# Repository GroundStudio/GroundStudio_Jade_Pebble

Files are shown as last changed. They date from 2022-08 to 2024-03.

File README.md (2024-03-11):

GroundStudio Jade Pebble
====================================
KASV939 (https://ardushop.ro/ro/placi-de-dezvoltare/1724-placa-de-dezvoltare-jade-pebble.html)

Get it from [ardushop.ro](https://ardushop.ro/ro/placi-de-dezvoltare/1724-placa-de-dezvoltare-jade-pebble.html)

Explore all the GroundStudio products at [GroundStudio.ro](https://groundstudio.ro/)

Description
-------------------
Very small SAMD21E18A based development board wih 48 MHz 32 bit processor, 256kBytes of Programmable Flash program memory, 32kBytes Internal SRAM, 6 Capacitive Touch sensing (PTC), 9 PWM Channels, 11 Digital Pins, 9 channel 12 bit ADC Pins and built in RGB NeoPixel LED.

Contents
-------------------

* [/Documentation](https://github.com/GroundStudio/GroundStudio_Jade_Pebble/tree/main/Documentation) -- Pinout.
* [/Hardware](https://github.com/GroundStudio/GroundStudio_Jade_Pebble/tree/main/Hardware) -- Schematics, layout.

Versions
-------------------
*(Not all tags shown)*

- [REV 0.1]

License
-------------------

This is released under the [Attribution-ShareAlike 4.0 International (CC BY-SA 4.0)](https://creativecommons.org/licenses/by-sa/4.0/) license.
**You are welcome to use this for commercial purposes.**

Please consider contributing back to this project or others to help the open-source hardware community continue to thrive and grow!

Certifications:

[Open Source Hardware Association](https://certification.oshwa.org/ro000005.html)   
   
certification-mark-RO000005-wide (https://certification.oshwa.org/ro000005.html)

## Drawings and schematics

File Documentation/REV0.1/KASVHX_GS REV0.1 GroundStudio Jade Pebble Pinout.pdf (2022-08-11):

# GroundStudio Jade Pebble

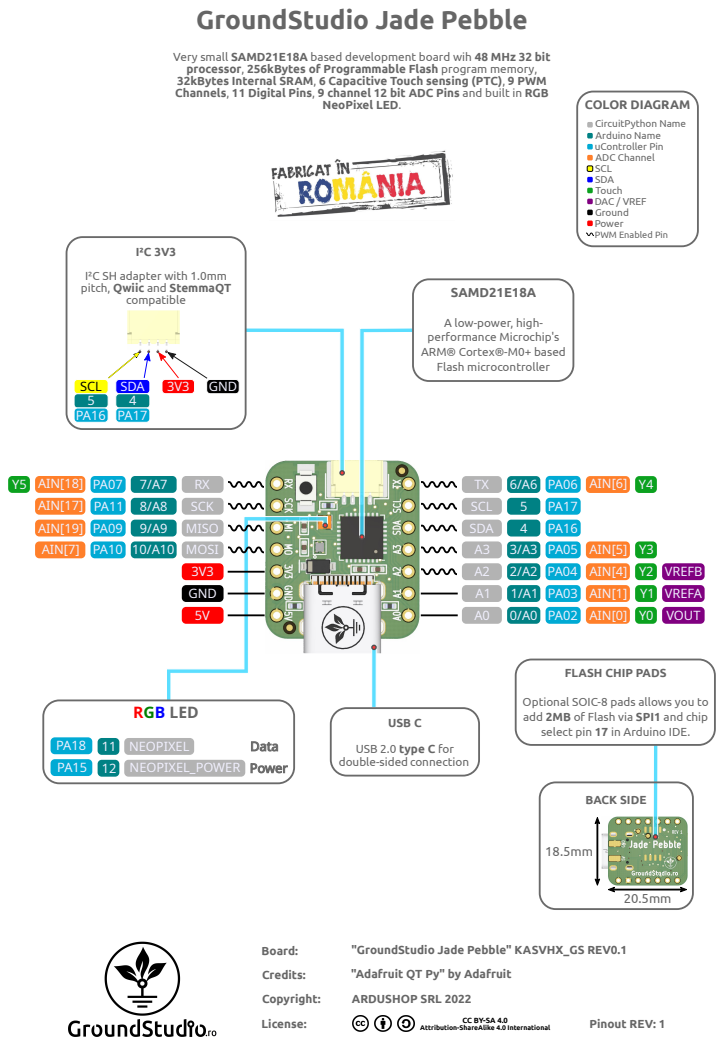
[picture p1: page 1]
TX 6/A6 PA06 AIN[6]; SCL; SDA; A3 3/A3 PA05 AIN[5] A2 2/A2 PA04 AIN[4] A1 1/A1 PA03 AIN[1]; PA02 AIN[0]; VOUT; VREFA; VREFB; 3V3 GND; RX SCK; PA07 PA11 PA09 9/A9 MISO PA10 10/A10 MOSI; AIN[18] AIN[17] AIN[19] AIN[7]; NEOPIXEL NEOPIXEL_POWER; RGB LED; Data Power; SAMD21E18A; NeoPixel LED.; BACK SIDE; USB C; I²C 3V3; compatible; SCL SDA 4 PA17; Copyright:; License:; ARDUSHOP SRL 2022; Pinout REV: 1; Board:; Credits:; "Adafruit QT Py" by Adafruit

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

COLOR DIAGRAM
CircuitPython Name
Arduino Name
uController Pin
ADC Channel
SCL
SDA
Touch
DAC / VREF
Ground
Power
PWM Enabled Pin

I²C SH adapter with 1.0mm
pitch, Qwiic and StemmaQT

A low-power, high-
performance Microchip's
ARM® Cortex®-M0+ based
Flash microcontroller

FLASH CHIP PADS

Optional SOIC-8 pads allows you to
add 2MB of Flash via SPI1 and chip
select pin 17 in Arduino IDE.

USB 2.0 type C for
double-sided connection

"GroundStudio Jade Pebble" KASVHX_GS REV0.1

Attribution-ShareAlike 4.0 International

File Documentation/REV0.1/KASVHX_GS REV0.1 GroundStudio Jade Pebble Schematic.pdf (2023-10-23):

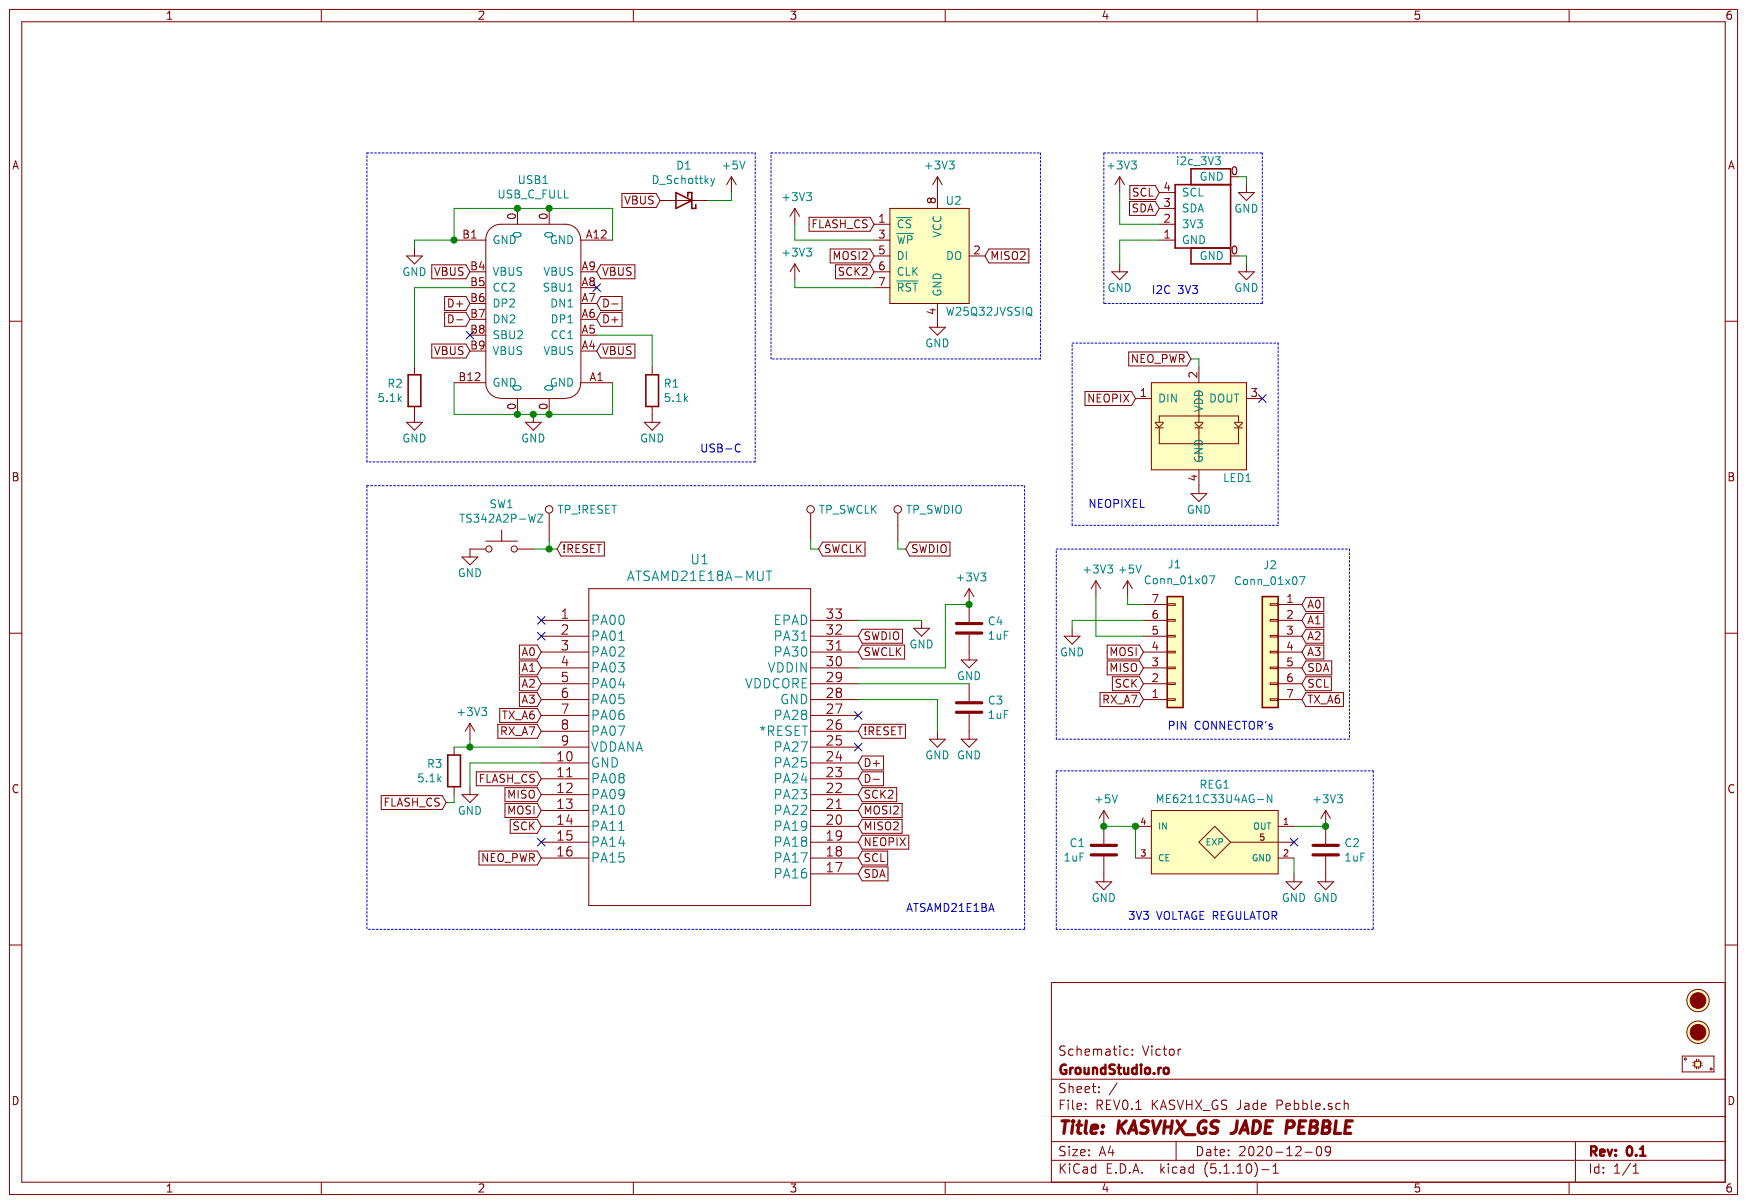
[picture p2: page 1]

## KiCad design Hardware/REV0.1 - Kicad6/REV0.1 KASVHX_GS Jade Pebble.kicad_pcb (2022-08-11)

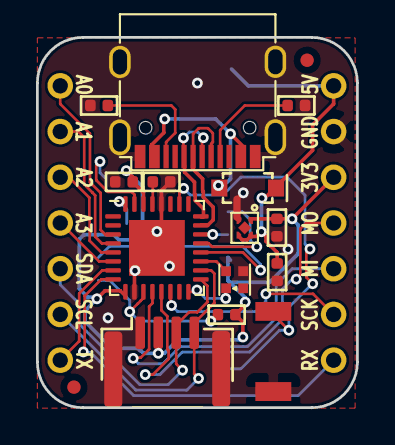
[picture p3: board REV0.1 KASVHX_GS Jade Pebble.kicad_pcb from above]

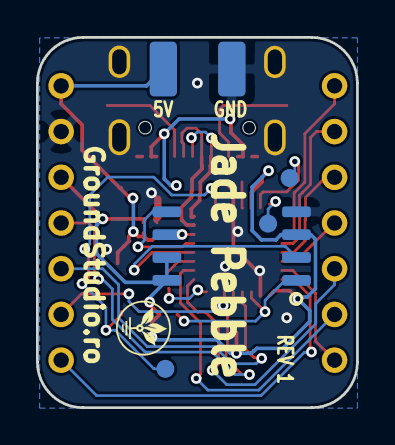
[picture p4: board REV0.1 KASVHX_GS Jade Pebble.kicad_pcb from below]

Board: 2 copper layers, 17.8 x 20.6 mm, 22 parts (3 on the bottom side), 29 nets.

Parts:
C1, C2, C3, C4: 1uF; C_0402_1005Metric
D1: D_Schottky; SOD-123
FID1, FID2: Fiducial; Fiducial_0.75mm_Mask1.5mm
J1, J2: Conn_01x07; PinHeader_1x07_P2.54mm_Slim_Vertical_Male
LED1: SK6805-EC15 DY-S1515065; SK6805-EC15
R1, R2, R3: 5.1k; R_0402_1005Metric
REG1: ME6211C33U4AG-N; FBP1-1-4
SW1: TS342A2P-WZ
TP1: TP_!RESET; TestPoint
TP2: TP_SWCLK; TestPoint
TP3: TP_SWDIO; TestPoint
U1: ATSAMD21E18A-MUT; QFN-32-1EP_5x5mm_P0.5mm_EP3.1x3.1mm
U2: W25Q32JVSSIQ; SOIC-8_5.23x5.23mm_P1.27mm
USB1: USB_C_FULL; USB_C_C167321
X1: i2c_3V3; SH__1x04_P1.00mm_Horizontal

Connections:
!RESET: SW1.2, TP1.~, U1.26
+3V3: C2.1, C4.1, J1.5, R3.1, REG1.1, U1.9, U1.30, U2.3, U2.7, U2.8, X1.2
+5V: C1.1, D1.1, J1.7, REG1.3, REG1.4
A0: J2.1, U1.3
A1: J2.2, U1.4
A2: J2.3, U1.5
A3: J2.4, U1.6
D+: U1.24, USB1.A6, USB1.B6
D-: U1.23, USB1.A7, USB1.B7
FLASH_CS: R3.2, U1.11, U2.1
GND: C1.2, C2.2, C3.2, C4.2, J1.6, LED1.4, R1.2, R2.2, REG1.2, SW1.1, U1.10, U1.28, U1.33, U2.4, USB1.0, USB1.A1, USB1.A12, USB1.B1, USB1.B12, X1.0, X1.1
MISO: J1.3, U1.12
MISO2: U1.20, U2.2
MOSI: J1.4, U1.13
MOSI2: U1.21, U2.5
NEOPIX: LED1.1, U1.19
NEO_PWR: LED1.2, U1.16
unnamed: C3.1, U1.29
unnamed: R1.1, USB1.A5
unnamed: R2.1, USB1.B5
RX_A7: J1.1, U1.8
SCK: J1.2, U1.14
SCK2: U1.22, U2.6
SCL: J2.6, U1.18, X1.4
SDA: J2.5, U1.17, X1.3
SWCLK: TP2.~, U1.31
SWDIO: TP3.~, U1.32
TX_A6: J2.7, U1.7
VBUS: D1.2, USB1.A4, USB1.A9, USB1.B4, USB1.B9

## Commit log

2022-08-11 - initial commit
    [REV0.1 KASVHX_GS Jade Pebble.kicad_pcb, REV0.1 KASVHX_GS Jade Pebble.kicad_sch]
2022-08-26 - added schematic pdf file
2022-08-26 - added "Kicad6" to revision folder name
    [REV0.1 KASVHX_GS Jade Pebble.kicad_pcb, REV0.1 KASVHX_GS Jade Pebble.kicad_sch]
2023-10-23 - fixed schematic title error
